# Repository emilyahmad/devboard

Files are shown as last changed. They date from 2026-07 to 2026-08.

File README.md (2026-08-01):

# Devboard

A simple devboard with some cute curious george motifs - my first hardware project/PCB, built using @KaiPereira's starter guide on stasis. Like any good devboard, the monkeyboard contains an SoC, memory, power management and I/O interfaces: it receives power via its USB-C connector port, maintains a quad SPI flash memory IC for data storage, 2 multipurpose switches, a crystal oscillator for precise electrical frequencies, and the star of the show, the RP2040 as its MCU.

### Assembled

| Front | Back | Plugged in |
| --- | --- | --- |
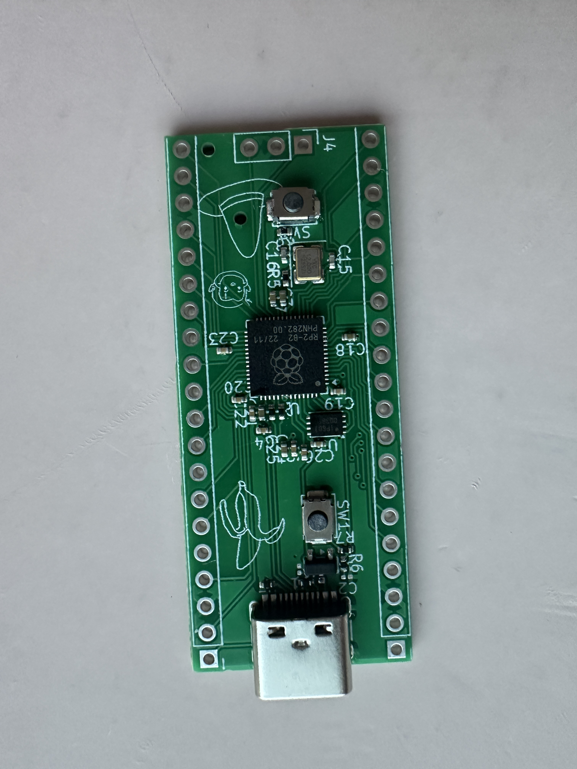
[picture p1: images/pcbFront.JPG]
front of pcb
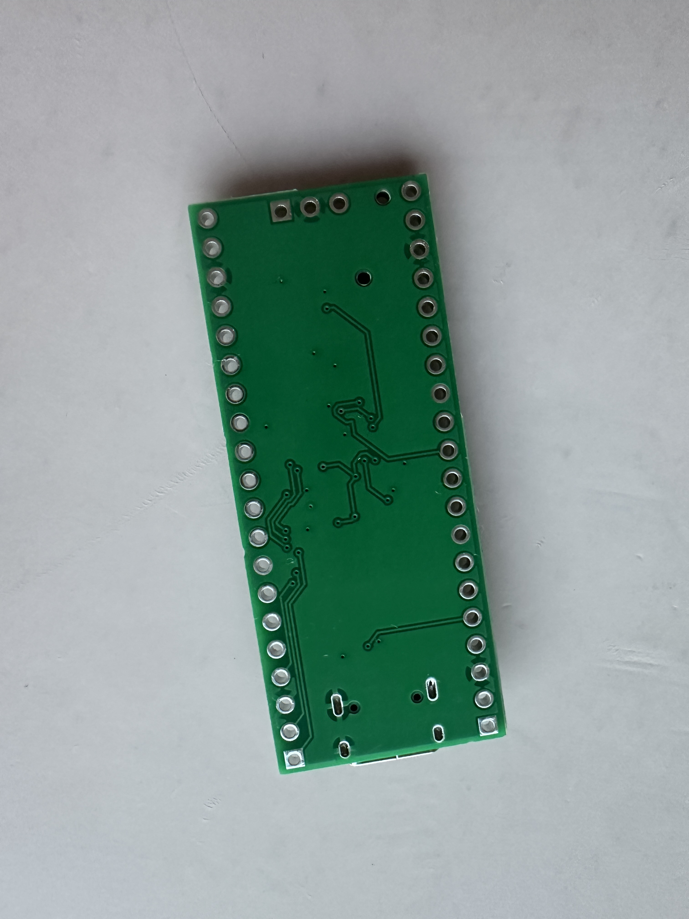
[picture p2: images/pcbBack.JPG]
back of pcb
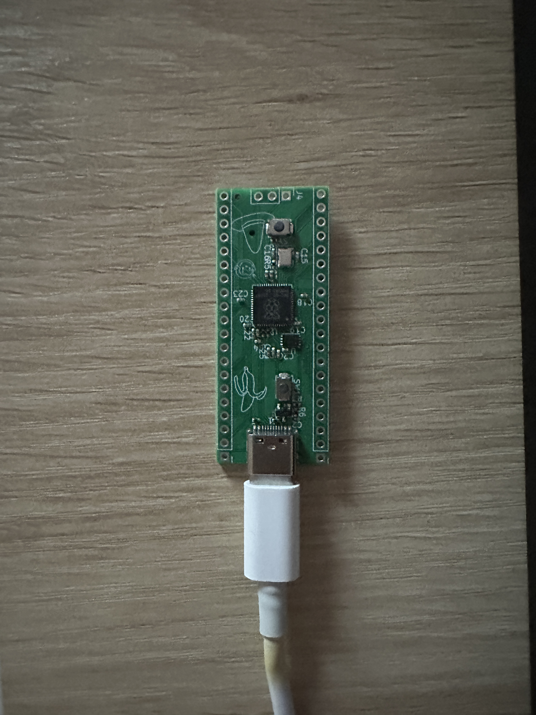
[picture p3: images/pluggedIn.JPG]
pcb plugged in
|  |  |  |

### Design

| Schematic | PCB | 3D Render |
| --- | --- | --- |
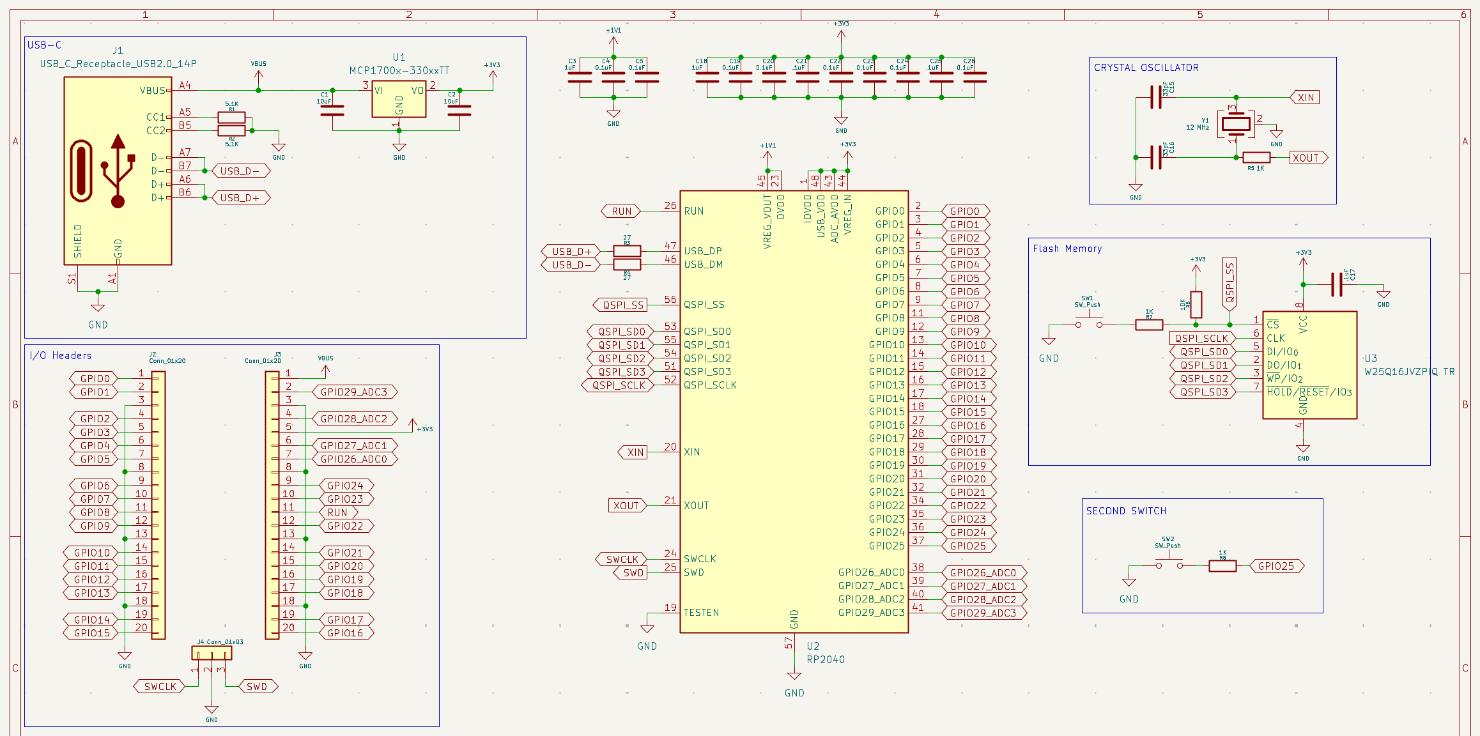
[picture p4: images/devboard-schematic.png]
Schematic
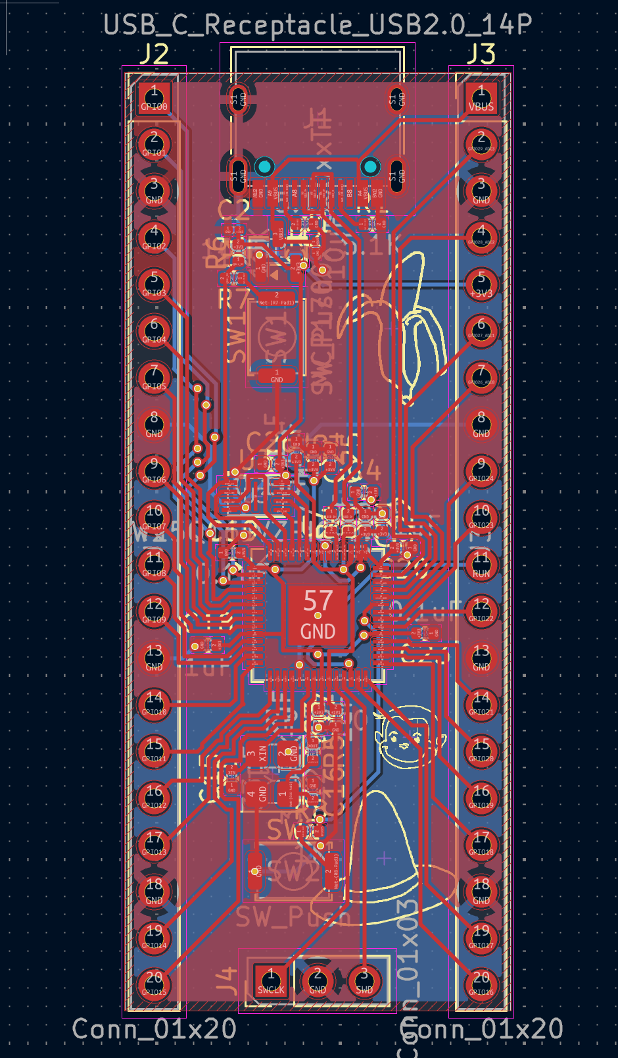
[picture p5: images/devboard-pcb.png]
PCB
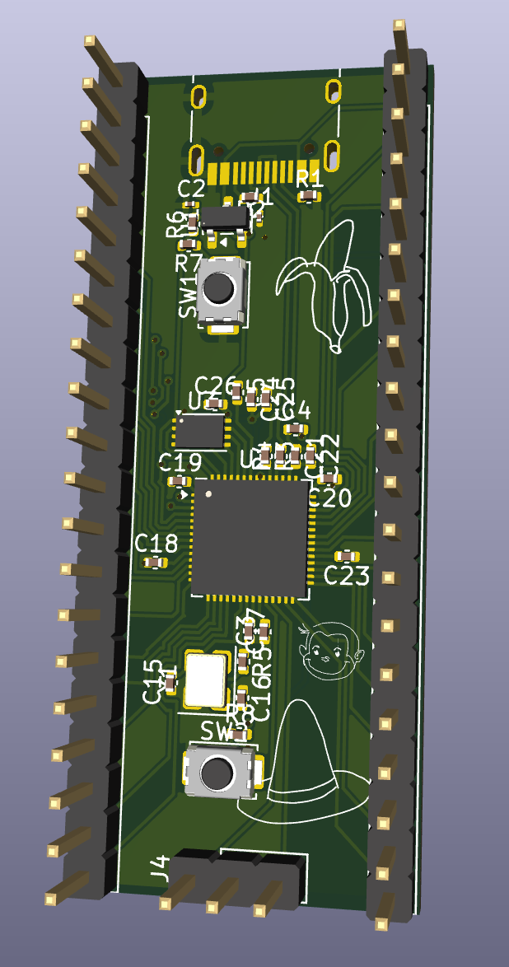
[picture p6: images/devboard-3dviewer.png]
3D
|  |  |  |

### BOM

| Item | Purpose | Quantity | Cost | Source |
| --- | --- | --- | --- | --- |
| C1, C2 | 10uF decoupling capacitor | 2 | $0.0800 | JLCPCB Basic (CL10A106KP8NNNC) |
| C3, C18 | 1uF decoupling capacitor | 2 | $0.0660 | JLCPCB Extended (GRM155R60J105KE19D) |
| C4, C5, C19, C20, C22, C23, C24, C26 | 0.1uF decoupling capacitor | 8 | $0.0845 | JLCPCB Basic (CL05B104KO5NNNC) |
| C15, C16 | 33pF crystal load capacitor  | 2 | $0.0130 | JLCPCB Basic (0402CG330J500NT) |
| C17, C21, C25 | 0.1uF decoupling capacitor | 3 | $0.0845 | JLCPCB Basic (CL05B104KO5NNNC) |
| J1 | USB-C receptacle | 1 | $0.9155 | JLCPCB Extended (TYPE-C-31-M-12) |
| J2, J3 | 20-pin GPIO header | 2 | — | Solder yourself |
| J4 | 3-pin SWD debug header | 1 | — | Solder yourself |
| R1, R2 | 5.1K CC pull-down resistor | 2 | $0.0090 | JLCPCB Basic (0402WGF5101TCE) |
| R3, R4 | 27Ω USB termination resistor | 2 | $0.0176 | JLCPCB Extended (0402WGF270JTCE) |
| R5, R7, R8 | 1K resistor | 3 | $0.0150 | JLCPCB Extended (RCT021KFLF) |
| R6 | 10K pull-up resistor | 1 | $0.0065 | JLCPCB Basic (0402WGF1002TCE) |
| SW1, SW2 | Push button | 2 | $0.5550 | JLCPCB Basic (TS-1088-AR02016) |
| U1 | MCP1700 3.3V LDO regulator | 1 | $2.4285 | JLCPCB Extended (MCP1700T-3302E/TT)  |
| U2 | RP2040 microcontroller | 1 | $4.8810 | JLCPCB Extended (RP2040) |
| U3 | W25Q16 16Mbit flash memory | 1 | $6.3910 | JLCPCB Extended (W25Q16JVZPIQ TR) |
| Y1 | 12MHz crystal oscillator | 1 | $0.8382 | JLCPCB Extended (XJHCELNANF-12MHZ) |

Total: $16.38

<!--
reference
|RP2040|$0.94|https://www.lcsc.com/product-detail/C2040.html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|
|Crystal oscillator|$0.07|https://www.lcsc.com/product-detail/C9002.html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|
|MCP1700 LDO, 3.3V|$0.98|https://www.lcsc.com/product-detail/C39051.html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|
|USB-C port, 16-pin|$0.08|https://www.lcsc.com/product-detail/C2988369.html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|
|W25Q128JVSIQ flash memory|$1.96|https://www.lcsc.com/product-detail/C97521.html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|
|PCM5102A DAC|$1.02|https://www.lcsc.com/product-detail/C107671.html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|
|PAM8302AAD speaker amplifier|$0.21|https://www.lcsc.com/product-detail/C112137.html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|
|BQ25185 battery charging IC|$1.66|https://www.lcsc.com/product-detail/C19725033.html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|
|SMD tactile switch, 6x6mm|$0.03|https://www.lcsc.com/product-detail/C49234152.html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|
|Pin headers|$0.38|https://www.lcsc.com/product-detail/C2938459.html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|
|PCB|$0.42|https://cart.jlcpcb.com/quote?stencilLayer=2&stencilWidth=21&stencilLength=54&stencilCounts=5&plateType=1|
|Stencil|$3.05|https://cart.jlcpcb.com/quote?stencilLayer=2&stencilWidth=21&stencilLength=54&stencilCounts=5&plateType=1|

Total: $10.81 ($7.76 w/o stencil)

# Notes

meow
-

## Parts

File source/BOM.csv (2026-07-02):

Id | Designator | Footprint | Quantity | Comment | Supplier and ref
1 | C1, C2 | C_0201_0603Metric | 2 | 10uF
2 | C3, C18 | C_0402_1005Metric | 2 | 1uF
3 | C4, C5, C19, C20, C22, C23, C24, C26 | C_0402_1005Metric | 8 | 0.1uF
4 | C15, C16 | C_0402_1005Metric | 2 | 33pF
5 | C17, C21, C25 | C_0402_1005Metric | 3 | .1uF
6 | J1 | USB_C_Receptacle_HRO_TYPE-C-31-M-12 | 1 | USB_C_Receptacle_USB2.0_14P
7 | J2, J3 | PinHeader_1x20_P2.54mm_Vertical | 2 | Conn_01x20
8 | J4 | PinHeader_1x03_P2.54mm_Vertical | 1 | Conn_01x03
9 | R1, R2 | C_0402_1005Metric | 2 | 5.1K
10 | R3, R4 | C_0402_1005Metric | 2 | 27
11 | R5, R7, R8 | C_0402_1005Metric | 3 | 1K
12 | R6 | C_0402_1005Metric | 1 | 10K
13 | SW1, SW2 | SW_Push_SPST_NO_Alps_SKRK | 2 | SW_Push
14 | U1 | SOT-23 | 1 | MCP1700x-330xxTT
15 | U2 | QFN-56-1EP_7x7mm_P0.4mm_EP3.2x3.2mm | 1 | RP2040
16 | U3 | Winbond_USON-8-1EP_3x2mm_P0.5mm_EP0.2x1.6mm | 1 | W25Q16JVZPIQ TR
17 | Y1 | Crystal_SMD_3225-4Pin_3.2x2.5mm | 1 | 12 MHz

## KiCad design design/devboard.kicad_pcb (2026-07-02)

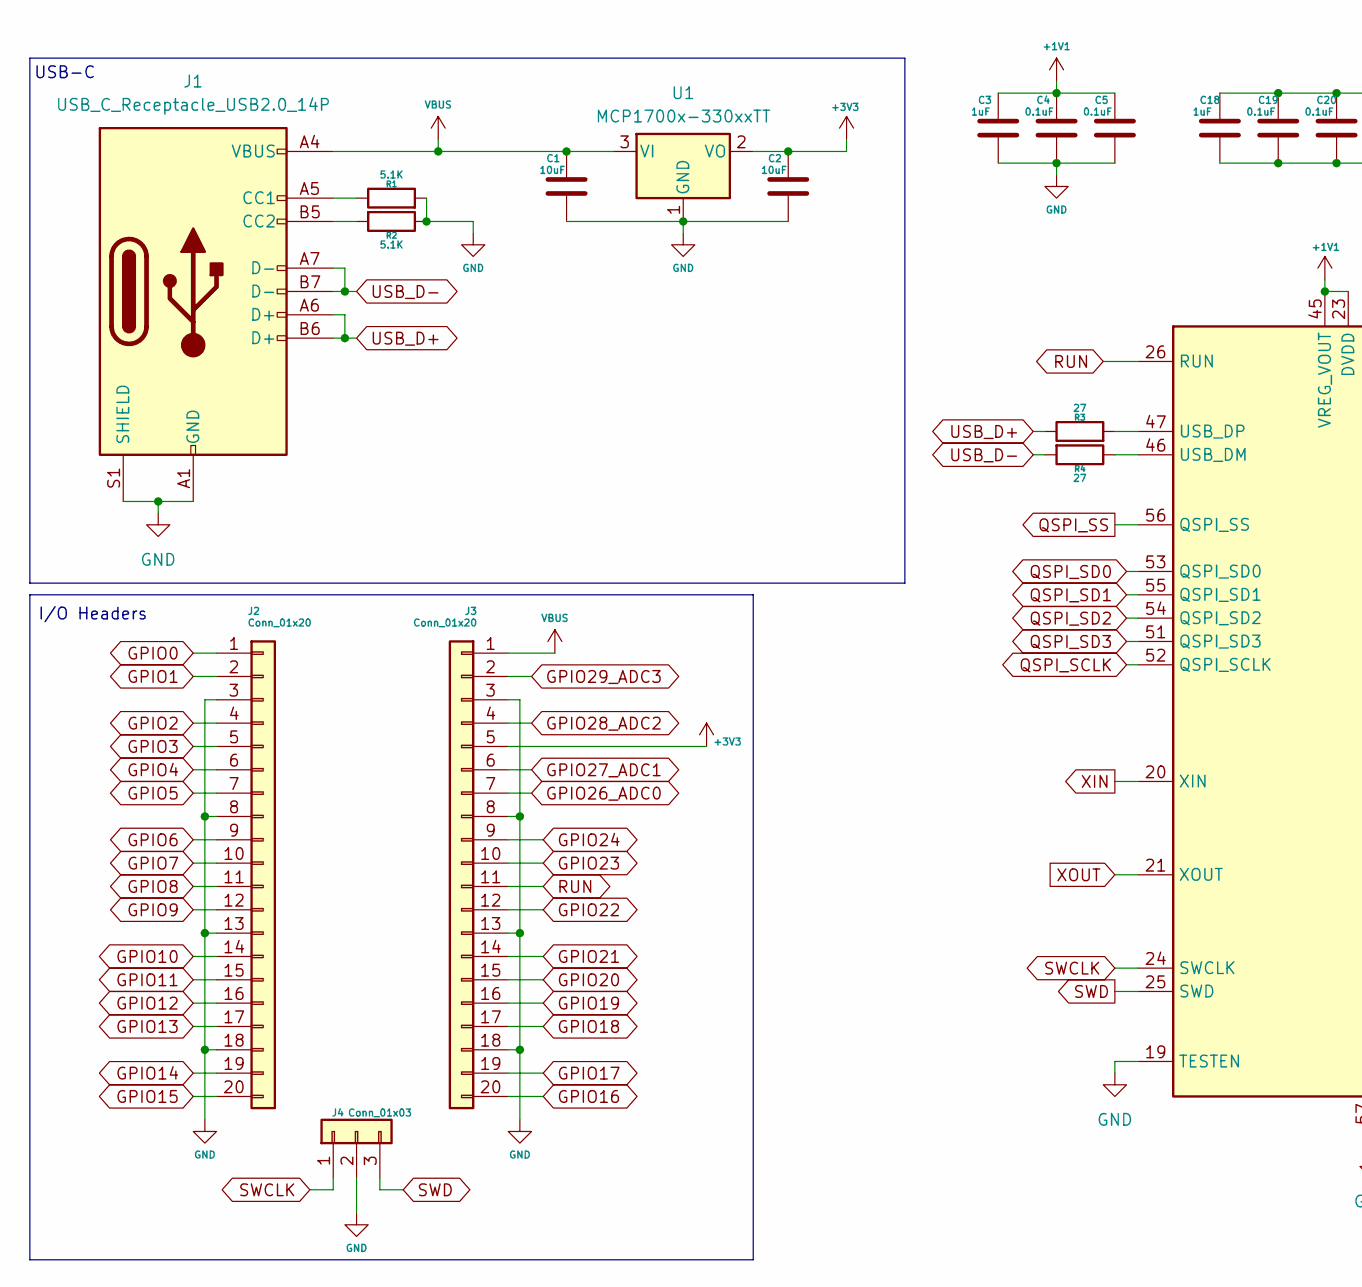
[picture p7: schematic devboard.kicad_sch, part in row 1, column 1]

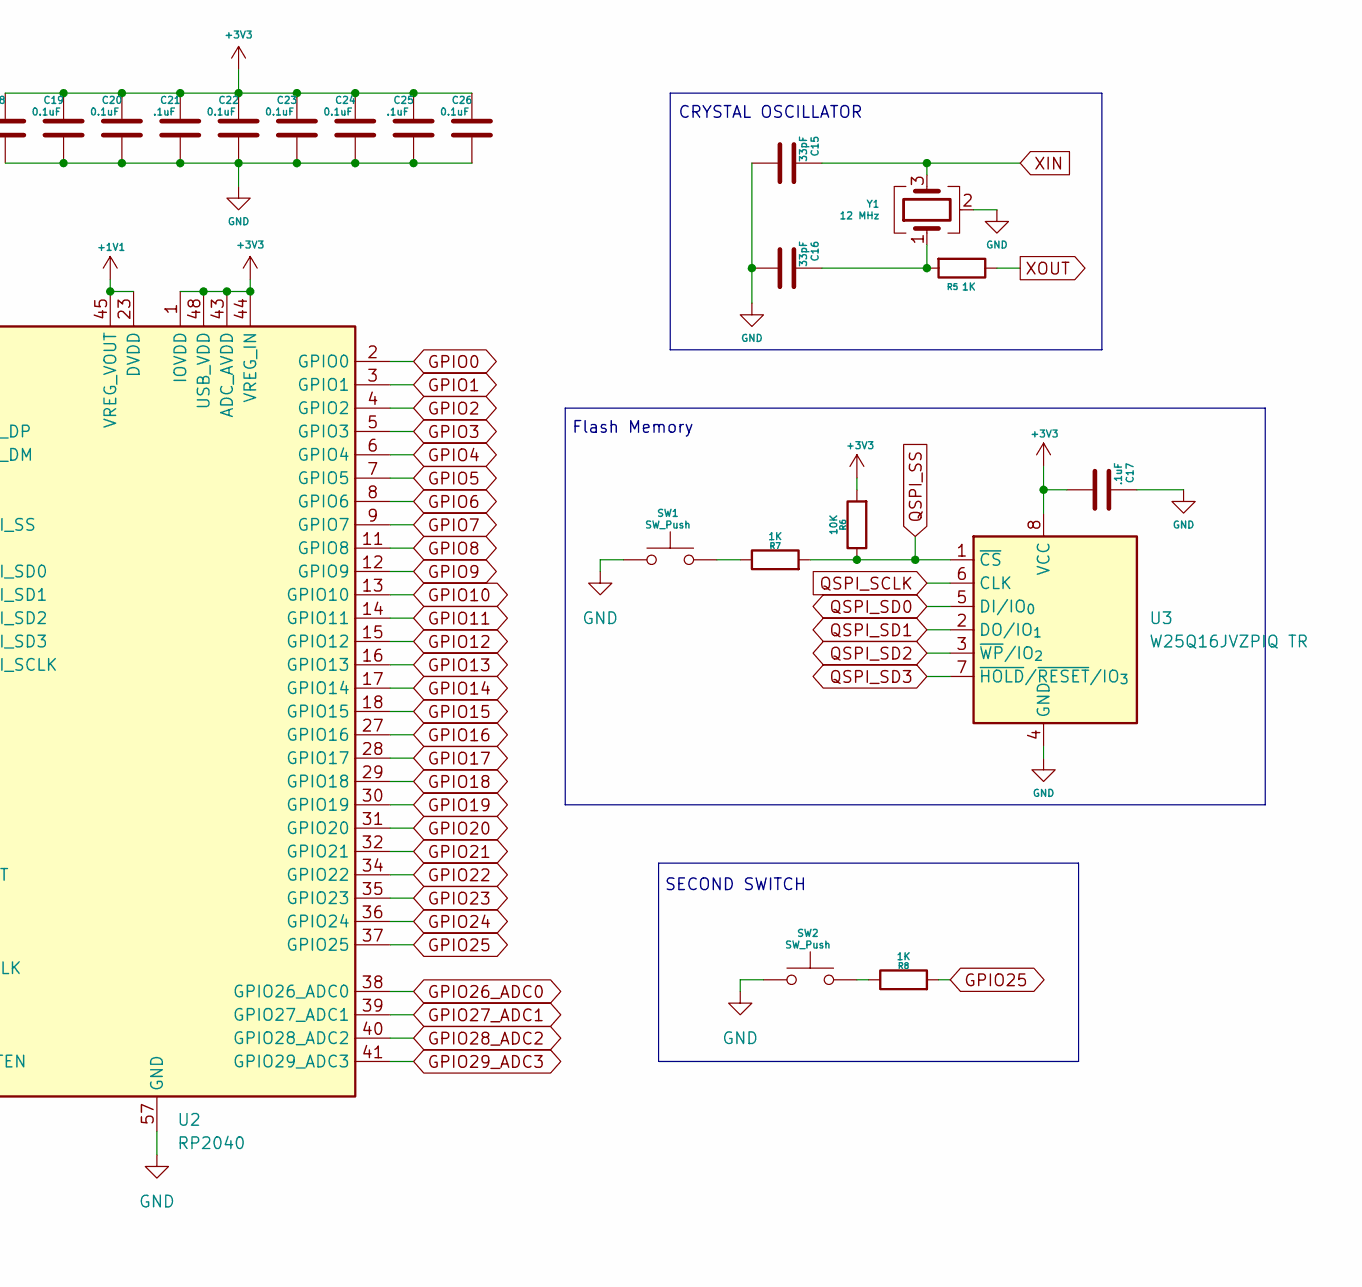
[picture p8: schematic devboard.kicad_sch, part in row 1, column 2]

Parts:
C1, C2: 10uF; C_0201_0603Metric
C3, C18: 1uF; C_0402_1005Metric
C4, C5, C19, C20, C22, C23, C24, C26: 0.1uF; C_0402_1005Metric
C15, C16: 33pF; C_0402_1005Metric
C17, C21, C25: .1uF; C_0402_1005Metric
J1: USB_C_Receptacle_USB2.0_14P; USB_C_Receptacle_HRO_TYPE-C-31-M-12
J2, J3: Conn_01x20; PinHeader_1x20_P2.54mm_Vertical
J4: Conn_01x03; PinHeader_1x03_P2.54mm_Vertical
R1, R2: 5.1K; C_0402_1005Metric
R3, R4: 27; C_0402_1005Metric
R5, R7, R8: 1K; C_0402_1005Metric
R6: 10K; C_0402_1005Metric
SW1, SW2: SW_Push; SW_Push_SPST_NO_Alps_SKRK
U1: MCP1700x-330xxTT; SOT-23
U2: RP2040; QFN-56-1EP_7x7mm_P0.4mm_EP3.2x3.2mm
U3: W25Q16JVZPIQ TR; Winbond_USON-8-1EP_3x2mm_P0.5mm_EP0.2x1.6mm
Y1: 12 MHz; Crystal_SMD_3225-4Pin_3.2x2.5mm

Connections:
+1V1: C3.2, C4.2, C5.2, U2.23 (DVDD), U2.45 (VREG_VOUT), U2.50 (DVDD)
+3V3: C2.2, C17.1, C18.2, C19.2, C20.2, C21.2, C22.2, C23.2, C24.2, C25.2, C26.2, J3.5, R6.2, U1.2 (VO), U2.1 (IOVDD), U2.10 (IOVDD), U2.22 (IOVDD), U2.33 (IOVDD), U2.42 (IOVDD), U2.43 (ADC_AVDD), U2.44 (VREG_IN), U2.48 (USB_VDD), U2.49 (IOVDD), U3.8 (VCC)
GND: C1.1, C2.1, C3.1, C4.1, C5.1, C15.1, C16.1, C17.2, C18.1, C19.1, C20.1, C21.1, C22.1, C23.1, C24.1, C25.1, C26.1, J1.A1 (GND), J1.A12 (GND), J1.B1 (GND), J1.B12 (GND), J1.S1 (SHIELD), J2.3, J2.8, J2.13, J2.18, J3.3, J3.8, J3.13, J3.18, J4.2, R1.2, R2.1, SW1.1, SW2.1, U1.1 (GND), U2.19 (TESTEN), U2.57 (GND), U3.4 (GND), Y1.2 (G), Y1.4 (G)
GPIO0: J2.1, U2.2 (GPIO0)
GPIO1: J2.2, U2.3 (GPIO1)
GPIO2: J2.4, U2.4 (GPIO2)
GPIO3: J2.5, U2.5 (GPIO3)
GPIO4: J2.6, U2.6 (GPIO4)
GPIO5: J2.7, U2.7 (GPIO5)
GPIO6: J2.9, U2.8 (GPIO6)
GPIO7: J2.10, U2.9 (GPIO7)
GPIO8: J2.11, U2.11 (GPIO8)
GPIO9: J2.12, U2.12 (GPIO9)
GPIO10: J2.14, U2.13 (GPIO10)
GPIO11: J2.15, U2.14 (GPIO11)
GPIO12: J2.16, U2.15 (GPIO12)
GPIO13: J2.17, U2.16 (GPIO13)
GPIO14: J2.19, U2.17 (GPIO14)
GPIO15: J2.20, U2.18 (GPIO15)
GPIO16: J3.20, U2.27 (GPIO16)
GPIO17: J3.19, U2.28 (GPIO17)
GPIO18: J3.17, U2.29 (GPIO18)
GPIO19: J3.16, U2.30 (GPIO19)
GPIO20: J3.15, U2.31 (GPIO20)
GPIO21: J3.14, U2.32 (GPIO21)
GPIO22: J3.12, U2.34 (GPIO22)
GPIO23: J3.10, U2.35 (GPIO23)
GPIO24: J3.9, U2.36 (GPIO24)
GPIO25: R8.2, U2.37 (GPIO25)
GPIO26_ADC0: J3.7, U2.38 (GPIO26_ADC0)
GPIO27_ADC1: J3.6, U2.39 (GPIO27_ADC1)
GPIO28_ADC2: J3.4, U2.40 (GPIO28_ADC2)
GPIO29_ADC3: J3.2, U2.41 (GPIO29_ADC3)
unnamed: C16.2, R5.2, Y1.1
unnamed: J1.A5 (CC1), R1.1
unnamed: J1.B5 (CC2), R2.2
unnamed: R7.1, SW1.2
unnamed: R8.1, SW2.2
unnamed: R4.1, U2.46 (USB_DM)
unnamed: R3.2, U2.47 (USB_DP)
QSPI_SCLK: U2.52 (QSPI_SCLK), U3.6 (CLK)
QSPI_SD0: U2.53 (QSPI_SD0), U3.5 (DI/IO_{0})
QSPI_SD1: U2.55 (QSPI_SD1), U3.2 (DO/IO_{1})
QSPI_SD2: U2.54 (QSPI_SD2), U3.3 (~WP/IO_{2})
QSPI_SD3: U2.51 (QSPI_SD3), U3.7 (~HOLD/~RESET/IO_{3})
QSPI_SS: R6.1, R7.2, U2.56 (QSPI_SS), U3.1 (~CS)
RUN: J3.11, U2.26 (RUN)
SWCLK: J4.1, U2.24 (SWCLK)
SWD: J4.3, U2.25 (SWD)
USB_D+: J1.A6 (D+), J1.B6 (D+), R3.1
USB_D-: J1.A7 (D-), J1.B7 (D-), R4.2
VBUS: C1.2, J1.A4 (VBUS), J1.A9 (VBUS), J1.B4 (VBUS), J1.B9 (VBUS), J3.1, U1.3 (VI)
XIN: C15.2, U2.20 (XIN), Y1.3
XOUT: R5.1, U2.21 (XOUT)

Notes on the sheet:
USB-C
SECOND SWITCH
Flash Memory
CRYSTAL OSCILLATOR
I/O Headers

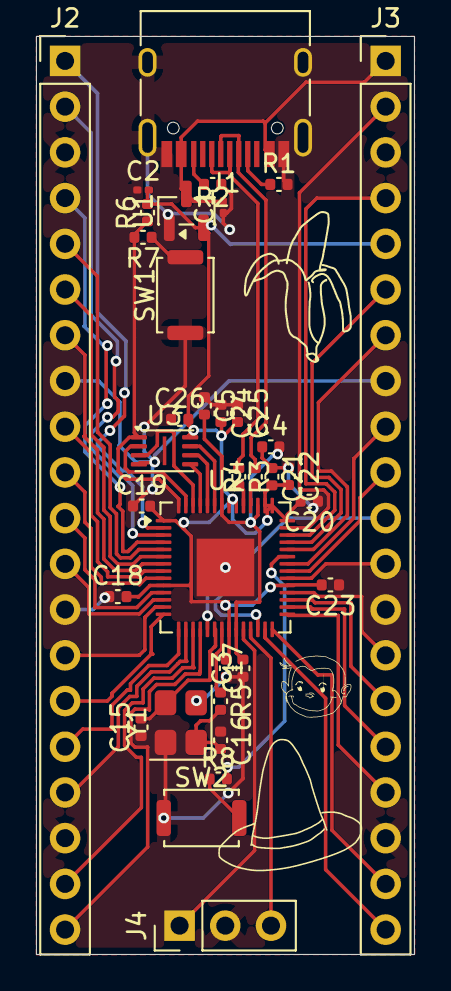
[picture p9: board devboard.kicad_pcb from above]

Board: 2 copper layers, 21.0 x 51.0 mm, 35 parts (0 on the bottom side), 54 nets.

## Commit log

2026-05-03 i dont even know what she saying cuz she foreign 😛
    [BOM.csv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]
2026-05-03 adding images
    Added schematic, PCB, and 3D viewer images to README.
2026-05-03 adding tables for images
    Updated project name and added detailed sections for schematic, PCB, and photos.
2026-05-03 added BOM
2026-05-04 organized files
    [BOM.csv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]
2026-07-02 Added assembly images
